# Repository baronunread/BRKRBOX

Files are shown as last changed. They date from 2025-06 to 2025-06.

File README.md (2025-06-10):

# BRKRBOX
Open Source GP2040-CE leverless controller with the focus of having the most addons without compromising the price.

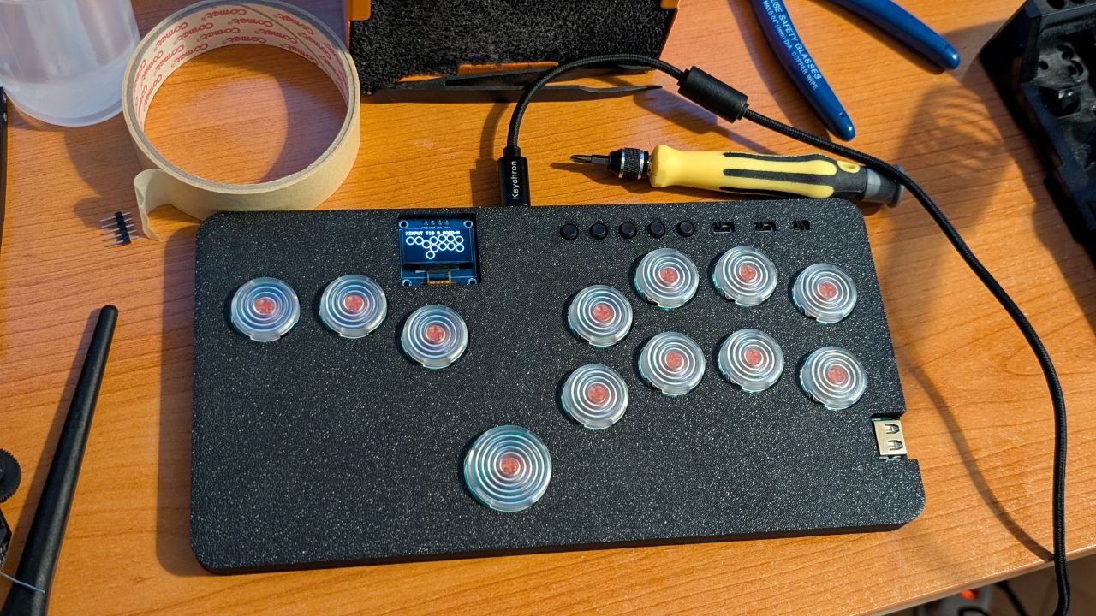
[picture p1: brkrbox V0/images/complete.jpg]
A picture of a completely built BRKRBOX V0

*Completely handsolderable!*

For the firmware do not refer to the standard GP-2040CE as the PCB/pin layout is very different and it's better to just download a precompiled firmware.
You can find the firmware ready for installation in the releases of [this repository](https://github.com/baronunread/BRKRBOX-GP2040-CE).

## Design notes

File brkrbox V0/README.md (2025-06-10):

# BRKRBOX V0

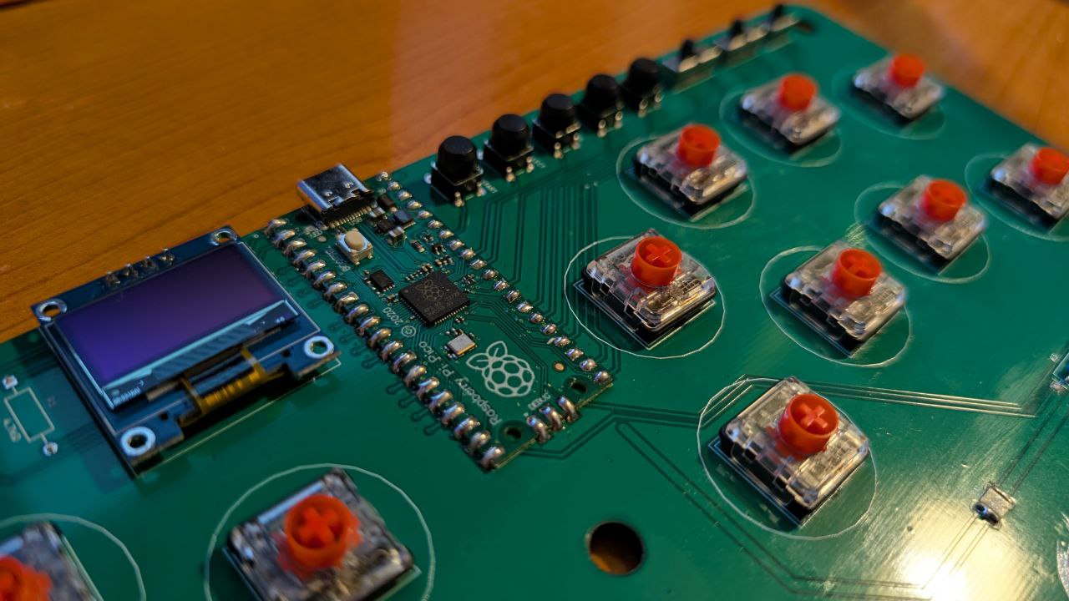
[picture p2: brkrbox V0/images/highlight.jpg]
The insides of the BRKRBOX V0


For this controller you will need to provide through your own printer and a PCB service these pieces:
- 1 * [3D printed case top and bottom](https://github.com/baronunread/BRKRBOX/tree/main/brkrbox%20V0/case)
- 1 * [PCB](https://github.com/baronunread/BRKRBOX/tree/main/brkrbox%20V0/pcb)

And you will need to purchase the following. I added a couple of links for some of the more tricky pieces, they're not referrals and I do not gain any money from them they're only for helping out in the building process.
- 5 * M3x10mm flat head screws
- 12 * Kailh Choc V2 **OR** 12 * Kailh Choc V1
- 12 * V2 Caps **OR** 12 V1 Caps. I grabbed [these V2 ones](https://www.aliexpress.com/item/1005007272793813.html)
- 1 * Raspberry Pi Pico
- 5 * 6x6x7mm tactile switches
- 5 * 6x6 tacticle switch caps. I grabbed [these ones](https://www.aliexpress.com/item/32846395636.html)
- 1 * 4 Pin I2C OLED 128 x 64 0.96inch. Make sure to grab something with the pinout like [these ones](https://www.aliexpress.com/item/1005006365881525.html). There's other ones where the VCC and GND are inverted, watch out! 
- 1 * Resettable Fuse 1812 500 mA. I grabbed [these ones](https://www.aliexpress.com/item/1005007077302451.html)
- 2 * 22R through hole resistors for the USB Peripheral

For easier purchase you should try to buy these from LCSC or buy valid replacements yourself. I'll provide the LCSC links down below:
- 1 * [Through hole USB A](https://lcsc.com/product-detail/USB-Connectors_SHOU-HAN-10-0-4C6-3-ZB_C6386909.html)
- 1 * [5P Slide Switch, 8.7x4.4mm](https://lcsc.com/product-detail/Slide-Switches_HanElectricity-SS12D07VG4_C22435633.html)
- 2 * [6P Slide Switch, 12.9x4.5mm](https://lcsc.com/product-detail/Slide-Switches_HanElectricity-SS13D07VG4_C22435636.html)

You might also need a small header to use it like so for the installation of the OLED Screen. This way it will lay flat:

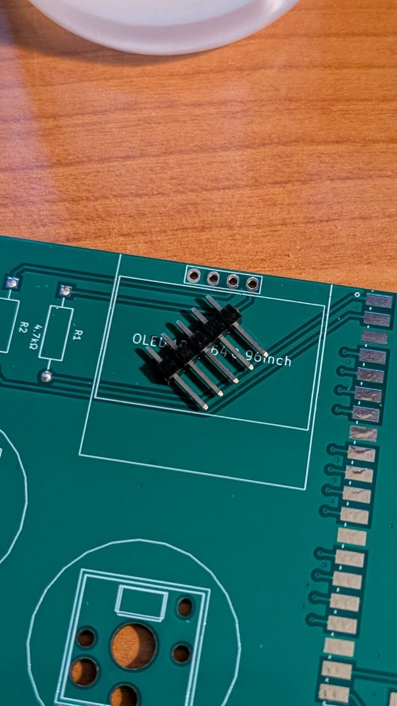
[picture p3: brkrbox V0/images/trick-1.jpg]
A small header laid on top of the OLED spot

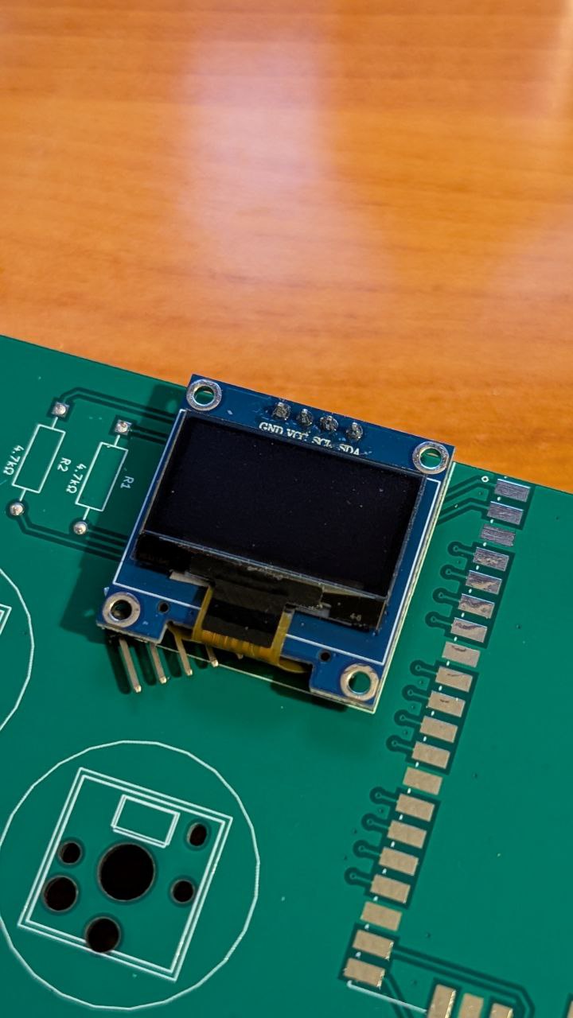
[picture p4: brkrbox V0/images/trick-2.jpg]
The OLED installed


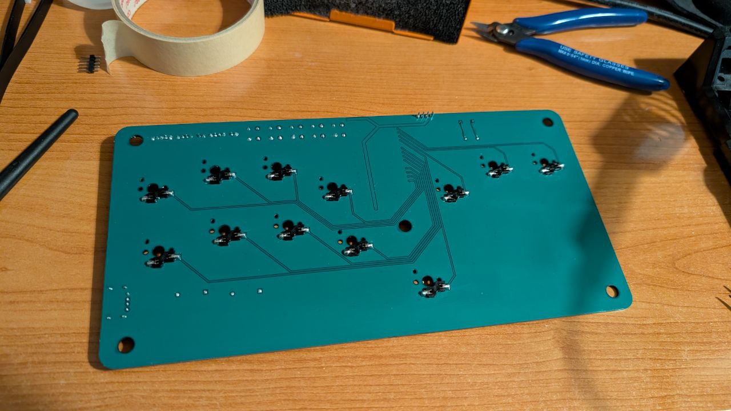
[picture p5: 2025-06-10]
brkrbox V0/images/bottom.jpg

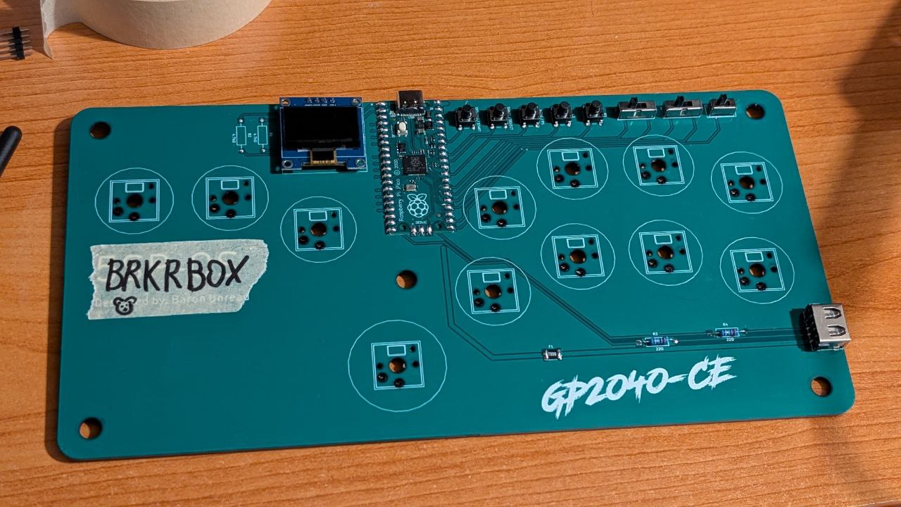
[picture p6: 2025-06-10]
brkrbox V0/images/top.jpg

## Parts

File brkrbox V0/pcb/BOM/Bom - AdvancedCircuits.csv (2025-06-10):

Component Description | QTY | Ref Des | Mfg P/N # | Manufacturer | Distributor P/N #
Connector | 12 | CIRCLE / B,CROSS / A,D,L,L1,L2,R,R1,R2,SQUARE / X,TRIANGLE / Y,U | CPG135001S30 | Dongguan City Kaihua Electronics Co., Ltd.
Fuse | 1 | F1 | MF-MSMF050-2 | Bourns Inc.
Switch | 5 | HOME / PS,L3,OPTIONS / START,R3,SHARE / SELECT
SS12D07VG4, SW_SS12D07VG4 | 1 | LOCK | SS12D07VG4
easyeda2kicad, SW-TH_SS13D07VG4 | 2 | LS/DP/RS,SOCD | SS13D07VG4
Display Device | 1 | OLED1
Resistor, 22Ω | 2 | R3,R4 | CFR-25JB-52-1K | Yageo
Evaluation Boards | 1 | U3 | SC0915 | Raspberry Pi
easyeda2kicad, USB-TH_10.0-4C6.3-ZB | 1 | USB | 10.0 4C6.3 ZB

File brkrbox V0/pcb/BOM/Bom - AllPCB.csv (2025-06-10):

Item # | Ref Des | Qty | Manufacturer | Mfg Part # | Description / Value | Package | Type | Your Instructions / Notes
1 | CIRCLE / B,CROSS / A,D,L,L1,L2,R,R1,R2,SQUARE / X,TRIANGLE / Y,U | 12 | Dongguan City Kaihua Electronics Co., Ltd. | CPG135001S30 | Connector
2 | F1 | 1 | Bourns Inc. | MF-MSMF050-2 | Fuse
3 | HOME / PS,L3,OPTIONS / START,R3,SHARE / SELECT | 5 |  |  | Switch
4 | LOCK | 1 |  | SS12D07VG4 | SS12D07VG4, SW_SS12D07VG4 | SW_SS12D07VG4
5 | LS/DP/RS,SOCD | 2 |  | SS13D07VG4 | easyeda2kicad, SW-TH_SS13D07VG4 | SW-TH_SS13D07VG4
6 | OLED1 | 1 |  |  | Display Device
7 | R3,R4 | 2 | Yageo | CFR-25JB-52-1K | Resistor, 22Ω
8 | U3 | 1 | Raspberry Pi | SC0915 | Evaluation Boards
9 | USB | 1 |  | 10.0 4C6.3 ZB | easyeda2kicad, USB-TH_10.0-4C6.3-ZB | USB-TH_10.0-4C6.3-ZB

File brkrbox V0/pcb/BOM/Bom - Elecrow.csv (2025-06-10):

*Reference | *Manufacturer Part number | *QTY | *Original | Description | Purchase Link
CIRCLE / B, CROSS / A, D, L, L1, L2, R, R1, R2, SQUARE / X, TRIANGLE / Y, U | CPG135001S30 | 12 |  | Kailh Choc hot swap socket footprint, supporting both Choc V1 and Choc V2 switches. Suggested LED placement varies slightly between the two versions - the V2 position is denoted by a much thinner silkscreen rectangle than the V1. The plate hole also has a difference in size of 0.015mm between V1 and V2; both sizes are shown by thin squares inside the outer perimeter square. | https://www.kailhswitch.com/mechanical-keyboard-switches/box-switches/choc-type-hot-swap-socket.html
F1 | MF-MSMF050-2 | 1 |  | Polymeric PTC Resettable Fuse 15V 500 mA Ih Surface Mount 1812 (4532 Metric), Concave #commonpartslibrary #ptc #Resettable-Fuses #polymeric #fuse #circuitprotection
HOME / PS, L3, OPTIONS / START, R3, SHARE / SELECT |  | 5 |  | Tactile Switch SPST-NO Top Actuated Through Hole, Outline 6.00mm x 6.00mm, Actuator Height off PCB, Vertical 5.00mm #switch #commonpartslibrary #Throughholetactilebutton
LOCK | SS12D07VG4 | 1 |  | Shouhan 8.7mm Package None https://www.snapeda.com/parts/SS12D07VG4/Shouhan/view-part/?ref=eda Manufacturer Recommendations 1 https://www.snapeda.com/parts/SS12D07VG4/Shouhan/view-part/?ref=snap SS12D07VG4 Switch Slide ON ON SPDT Top Slide 0.3A 30VDC PC Pins Bracket Mount/Through Hole Automotive Bulk Not in stock Shouhan
LS/DP/RS, SOCD | SS13D07VG4 | 2 |  | SS13D07VG4 Switches/Slide Switches HanElectricity Plugin-6P,12.9x4.5mm
OLED1 |  | 1 |  | I2C Display Module 0.96 Inch I2C SSD1306 OLED Display Module
R3, R4 | CFR-25JB-52-1K | 2 |  | 1 kOhms ±5% 0.25W, 1/4W Through Hole Resistor Axial Carbon Film #CommonPartLibrary #ThroughHole #Resistor #Axial
U3 | SC0915 | 1 |  | Pi Pico board with USB C! This model doesn't reflect the reality of the pin holes. What's important about this model is the USB C size and position to better help 3D modelling. This is V1 which has a port further away from the side of the PCB. RP2040 Raspberry Pi Pico - ARM® Cortex®-M0+ MCU 32-Bit Embedded Evaluation Board #part
USB | 10.0 4C6.3 ZB | 1 |  | LCSC: C6386909 1.5A USB 2.0 1 Bend-in 4P Mother -25℃~+85℃ Type-A Plugin USB Connectors ROHS

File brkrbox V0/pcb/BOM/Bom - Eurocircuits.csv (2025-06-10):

Reference designators | Quantity | MPN | Manufacturer | Part description | Value | SPN | Supplier | Package
CIRCLE / B,CROSS / A,D,L,L1,L2,R,R1,R2,SQUARE / X,TRIANGLE / Y,U | 12 | CPG135001S30 | Dongguan City Kaihua Electronics Co., Ltd. | Connector
F1 | 1 | MF-MSMF050-2 | Bourns Inc. | Fuse
HOME / PS,L3,OPTIONS / START,R3,SHARE / SELECT | 5 |  |  | Switch
LOCK | 1 | SS12D07VG4 |  | SS12D07VG4, SW_SS12D07VG4 |  |  |  | SW_SS12D07VG4
LS/DP/RS,SOCD | 2 | SS13D07VG4 |  | easyeda2kicad, SW-TH_SS13D07VG4 |  |  |  | SW-TH_SS13D07VG4
OLED1 | 1 |  |  | Display Device
R3,R4 | 2 | CFR-25JB-52-1K | Yageo | Resistor, 22Ω | 22Ω
U3 | 1 | SC0915 | Raspberry Pi | Evaluation Boards
USB | 1 | 10.0 4C6.3 ZB |  | easyeda2kicad, USB-TH_10.0-4C6.3-ZB |  |  |  | USB-TH_10.0-4C6.3-ZB

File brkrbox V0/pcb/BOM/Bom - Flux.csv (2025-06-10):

Designator | Quantity | Element UIDs | Part UID | Specification | Part Type | Domain | Compliance | JLCPCB Part Class | Operating Voltage | Operating Temperature | Reliability Target (MTBF) | Role | Software | Connector Type | Connector Gender | Connector Pitch | Connector Positions | Connector Rows | Power Requirements | Connectivity | Human Interface | Manufacturing Quantity Target | Manufacturer Part Number | LCSC Part Number | Digi-Key Part Number | Mouser Part Number | Arrow Part Number | Verical Part Number | Allow Substitutes | Manufacturer Name | Price Change Threshold | Lead Time Change Threshold | Pricing Notification Frequency | Preferred Distributors | Datasheet URL | License | Package or Case Code | Terminal Type | Pin Type | Voltage | Voltage Rating | Forward Voltage | Reverse Voltage | Max Reverse Voltage | Diode Type | Mount | Integrated Circuit Type | Breakdown Voltage | Threshold Voltage | Max Output Voltage | Max Input Voltage | Initial Voltage on Reset | Resistance | Resistor Type | Gate Resistance | On Resistance | Off Resistance | Tolerance | Capacitance
CIRCLE / B,CROSS / A,D,L,L1,L2,R,R1,R2,SQUARE / X,TRIANGLE / Y,U | 12 | 13cbca65-7ebb-486c-8d7f-457980dd5f42,1dd02d73-f855-4ed9-bb61-48d7afdcbc1c,453788c1-87dc-436e-9927-3020733b92b4,5d4ee873-0b57-4fdc-8f80-dae8822f14f7,6c7e672f-5785-4b4e-873f-adca0748fda5,81315eb5-8752-4c02-9645-b0ff8c188248,a0441abd-54a7-4999-b79a-3d6f6a0daa26,ad92d69b-570b-455e-b400-aaea4a4696e6,b1753d5a-5df8-4ec3-9620-e70979cbd7c6,cfa60faf-26f1-4c30-bce9-9d1356d2dff3,d8795130-e907-4a44-bf2e-a0b2fac38f54,ee1c7578-294d-4625-b657-05e465cbf97e | 9df5cfbc-3998-4718-8aa9-36a4037fda2c | Connector | Connector |  |  |  |  |  |  |  |  |  |  |  |  |  |  |  |  |  | CPG135001S30 | C5333465 |  |  |  |  |  | Dongguan City Kaihua Electronics Co., Ltd. |  |  |  |  | https://www.kailhswitch.com/Content/upload/pdf/202115927/CPG135001S30-data-sheet.pdf?rnd=914
F1 | 1 | 54df89ed-a35b-45bf-b589-2bc7090a49e8 | 4654e094-f07c-4f6e-8b10-5fe055fa02f0 | Fuse | Fuse |  |  |  |  |  |  |  |  |  |  |  |  |  |  |  |  |  | MF-MSMF050-2 |  |  |  |  |  |  | Bourns Inc. |  |  |  |  | https://www.bourns.com/docs/product-datasheets/mf-msmf.pdf | https://creativecommons.org/licenses/by/4.0/
HOME / PS,L3,OPTIONS / START,R3,SHARE / SELECT | 5 | 287cc951-31c7-404b-94b4-471d3b1a05ef,5ec2d293-5811-4514-94ff-05b435ea348d,c2c98e9e-a4b6-4d18-ba71-b09c7c508b4c,d08bcd25-ddcc-4e95-9254-595dcdd96963,f8e9c163-9e8b-4f6a-9ce8-96bd65f57ab5 | 6621bf74-6de6-4bc5-9a09-22b738c79d7c | Switch | Switch |  |  |  |  |  |  |  |  |  |  |  |  |  |  |  |  |  |  |  |  |  |  |  |  |  |  |  |  |  |  | https://creativecommons.org/licenses/by/4.0/
LOCK | 1 | b3431def-e53b-4c22-9ebf-fc8eb9cb41e4 | a580b38c-03da-4d61-a8a2-31617cd11a2f | SS12D07VG4, SW_SS12D07VG4 | SS12D07VG4 |  |  |  |  |  |  |  |  |  |  |  |  |  |  |  |  |  | SS12D07VG4 |  |  |  |  |  |  |  |  |  |  |  |  |  | SW_SS12D07VG4
LS/DP/RS,SOCD | 2 | 1212ffdf-8eab-4c5a-85b3-d13c85d3489d,e31c5a26-f8eb-409b-918a-10cdb260db2c | 930e0f6f-7281-4aa4-8b00-dbca88fa3728 | easyeda2kicad, SW-TH_SS13D07VG4 | easyeda2kicad |  |  |  |  |  |  |  |  |  |  |  |  |  |  |  |  |  | SS13D07VG4 | C2681578 |  |  |  |  |  |  |  |  |  |  |  |  | SW-TH_SS13D07VG4
OLED1 | 1 | 7118ac6a-ac36-43c4-a1ce-52e2071ad638 | e9b94ed6-9ec7-49ea-977f-5ef6a03148f5 | Display Device | Display Device
R3,R4 | 2 | dc189e78-9065-4a56-86dc-b8604abad575,e159507c-da5e-4621-a2ba-aea7c306b80d | a7555faa-9c91-463c-b9c5-25077c127dae | Resistor, 22Ω | Resistor |  |  |  |  |  |  |  |  |  |  |  |  |  |  |  |  |  | CFR-25JB-52-1K |  |  |  |  |  |  | Yageo |  |  |  |  | https://www.yageo.com/upload/media/product/app/datasheet/lr/yageo-cfr_datasheet.pdf | https://creativecommons.org/licenses/by/4.0/ |  |  |  |  |  |  |  |  |  |  |  |  |  |  |  |  | 22Ω
U3 | 1 | c9df00f1-e15e-4b05-9cc1-d62ee2f4c0a6 | 779e3cab-05c3-4748-8aa9-c15358300ae4 | Evaluation Boards | Evaluation Boards |  |  |  |  |  |  |  |  |  |  |  |  |  |  |  |  |  | SC0915 |  |  |  |  |  |  | Raspberry Pi |  |  |  |  | https://datasheets.raspberrypi.com/pico/pico-datasheet.pdf
USB | 1 | 06dd1929-d8d4-4774-9826-e0812e4d3b07 | a64464e9-188b-498c-bd67-841f3f16f068 | easyeda2kicad, USB-TH_10.0-4C6.3-ZB | easyeda2kicad |  |  |  |  |  |  |  |  |  |  |  |  |  |  |  |  |  | 10.0 4C6.3 ZB | C6386909 |  |  |  |  |  |  |  |  |  |  |  |  | USB-TH_10.0-4C6.3-ZB
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

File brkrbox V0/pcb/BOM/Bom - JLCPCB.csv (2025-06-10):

Comment | Designator | Footprint | JLCPCB Part #
CPG135001S30 | CIRCLE / B, CROSS / A, D, L, L1, L2, R, R1, R2, SQUARE / X, TRIANGLE / Y, U
MF-MSMF050-2 | F1
Switch | HOME / PS, L3, OPTIONS / START, R3, SHARE / SELECT
SS12D07VG4 | LOCK | SW_SS12D07VG4
SS13D07VG4 | LS/DP/RS, SOCD | SW-TH_SS13D07VG4
Display Device | OLED1
CFR-25JB-52-1K | R3, R4
SC0915 | U3
10.0 4C6.3 ZB | USB | USB-TH_10.0-4C6.3-ZB

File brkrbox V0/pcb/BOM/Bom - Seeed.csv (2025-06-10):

Designator | Manufacturer Part Number or Seeed SKU | QTY | Link
CIRCLE / B,CROSS / A,D,L,L1,L2,R,R1,R2,SQUARE / X,TRIANGLE / Y,U | CPG135001S30 | 12 | https://www.kailhswitch.com/Content/upload/pdf/202115927/CPG135001S30-data-sheet.pdf?rnd=914
F1 | MF-MSMF050-2 | 1 | https://www.bourns.com/docs/product-datasheets/mf-msmf.pdf
HOME / PS,L3,OPTIONS / START,R3,SHARE / SELECT |  | 5
LOCK | SS12D07VG4 | 1
LS/DP/RS,SOCD | SS13D07VG4 | 2
OLED1 |  | 1
R3,R4 | CFR-25JB-52-1K | 2 | https://www.yageo.com/upload/media/product/app/datasheet/lr/yageo-cfr_datasheet.pdf
U3 | SC0915 | 1 | https://datasheets.raspberrypi.com/pico/pico-datasheet.pdf
USB | 10.0 4C6.3 ZB | 1

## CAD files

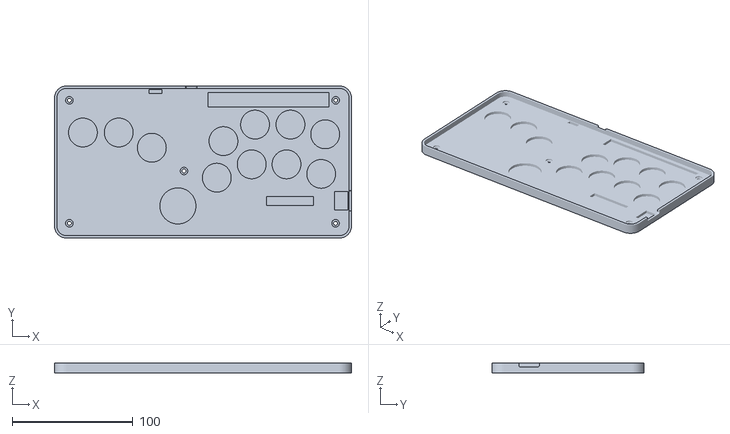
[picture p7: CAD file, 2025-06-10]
brkrbox V0/case/Bottom.stl
246.0 x 126.1 x 8.50

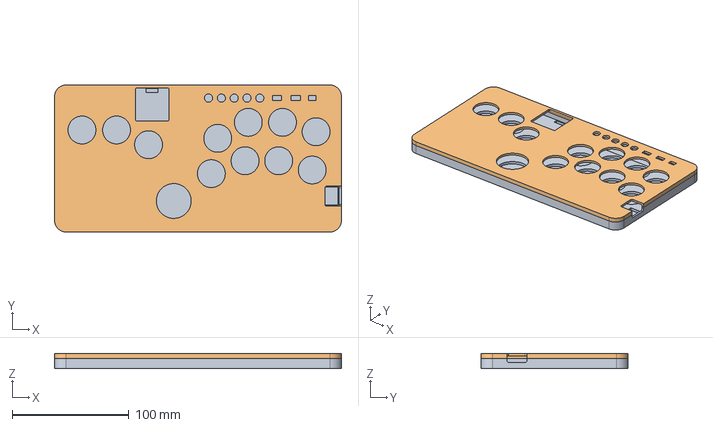
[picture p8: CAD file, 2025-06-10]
brkrbox V0/extras/brkrbox-v0.step
246.0 x 126.1 x 12.5 mm

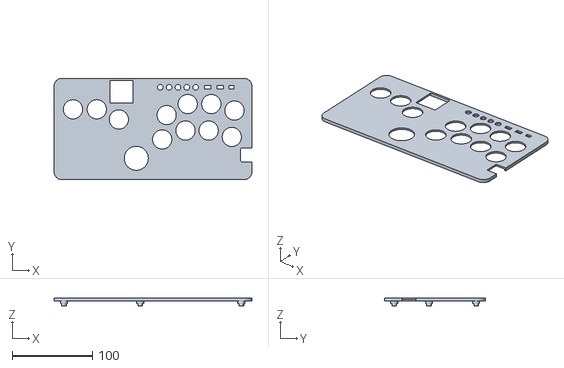
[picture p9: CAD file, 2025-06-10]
brkrbox V0/case/Top.stl
246.0 x 126.1 x 10.2

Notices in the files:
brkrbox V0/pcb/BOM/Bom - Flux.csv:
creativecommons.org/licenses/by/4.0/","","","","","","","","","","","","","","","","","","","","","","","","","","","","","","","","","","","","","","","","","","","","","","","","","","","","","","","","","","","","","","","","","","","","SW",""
